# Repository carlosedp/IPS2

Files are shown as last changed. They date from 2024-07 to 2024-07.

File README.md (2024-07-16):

# IPS2

The infamous interruptible power supply is back version 2 with usbC and more mmpfh (700mA@12V / 500mA@-12V).

IPS is a 2HP opensource (cc-by-sa-nc) eurorack module. It’s a switched-mode power supply that converts the 5V power from any USB type C interface/charger into +12V/-12V for your modular synthesizer. This does not allow you to power big racks but can easily power up small to medium size systems (check powerconsumption with f.e. modulargrid.net)
You can also use the unit without frontpanel inside a case (no access to the SHUT inputs) if it has a power switch and a 5V input.

Unlike IPS1 this module is built around a monolytic IC which houses two independent regulators, the TPS65131 from TI. It still has the infamous shutdown inputs for the regulators, which are accessible thru two jacks on the frontpanel.
Quote from IPS1: “This gives you a very different approach to operate a connected module. By “proper” modulation of it’s own powersupply voltages any connected module(s) can operate then in a, let’s say:  “near death state”, which can create interesting effects.

DISCLAIMER:
The shutdown inputs are a very experimental feature for those who like to experiment on their own risk with reduced or chopped supply voltages for their modules/setup. We take no responibility for damage or the like. (should not occur, cause no inversion of voltage is possible, only reduction of voltage is possible)

In a glimpse:

- modern and fast 1.25MHz switching regulator from Texas Instruments deliver up to 700mA@12V and 500mA@-12V
- IPS mainboard can be mounted inside a case without frontpanel like a common PSU (flatmount, has 2nd location for USB C connector and also pads for wires)
- cheap – can be used with any USB type C charger
- it’s friggin tiny

In this fork, I've replaced the USB connectors to some more available on JLCPCB.

Also I've added a front-panel design that is connected to the PCB with break-tabs so they can
be easily manufactured in one run and separated. Components also have JLCPCB part numbers.

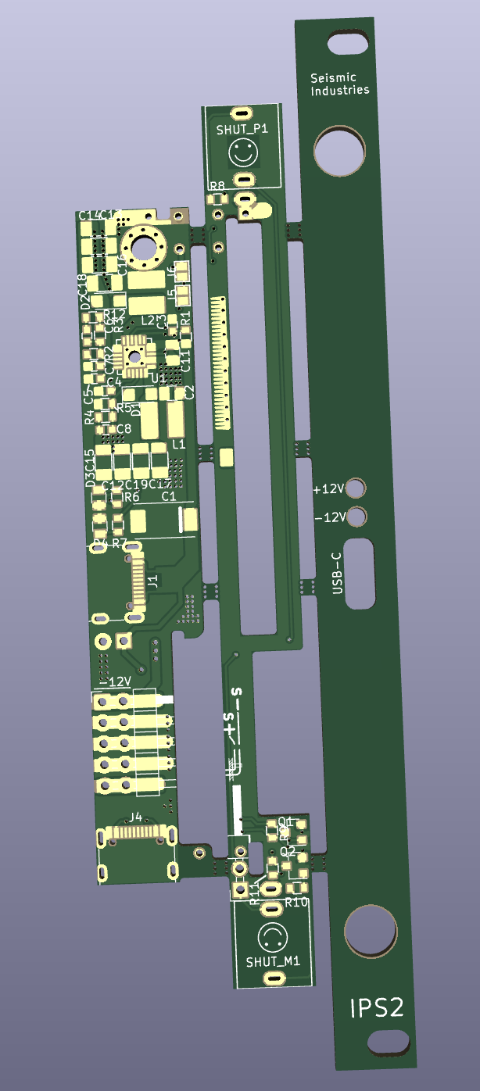
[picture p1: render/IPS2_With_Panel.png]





I/O:

- SHUT +12V deactivates the swiching regulator for the positive rail
- SHUT -12V deactivates the switching regulator for the negative rail
- internal 10 pin molex output header

Power Output:

- +12V 700mA / -12V 500mA (if incoming USB interface delivers it)

Dimensions:

- Width: 2 HP (10mm)
- Depth: 13mm

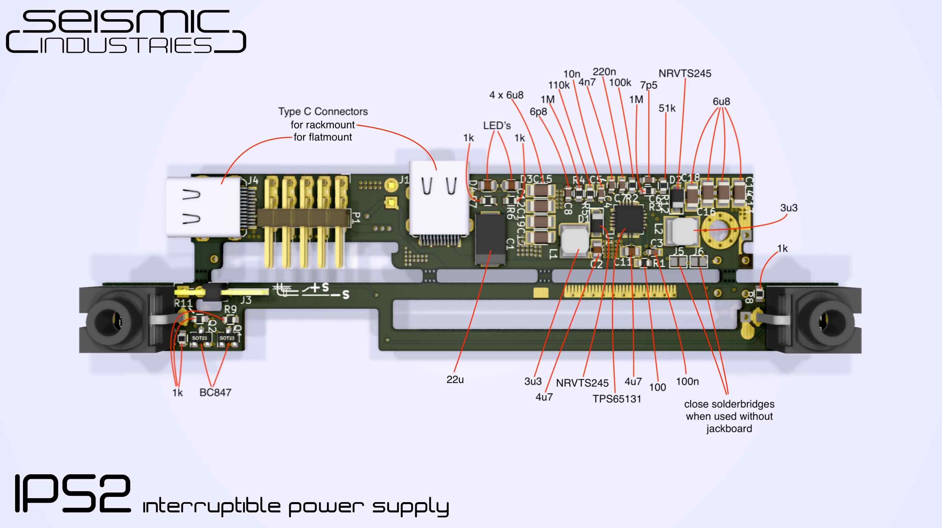
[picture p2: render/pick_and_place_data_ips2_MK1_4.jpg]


## License

CC-BY-SA-NC license

by seismic industries / 2019

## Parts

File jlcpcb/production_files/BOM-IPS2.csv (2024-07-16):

Comment | Designator | Footprint | LCSC
4u7 | L1,L2 | Inductor_SRN4018TA_bourns | C1330726
100n | C3 | C_0603 | C14663
Q_NPN_BEC | Q1,Q2 | SOT-23 | C150094
NRVTS245 | D1,D2 | D_SOD-123F | C154804
6p8 | C8 | C_0603 | C1679
4u7 | C11,C2 | C_0805 | C1779
220n | C7 | C_0603 | C21120
1k | R10,R11,R6,R7,R8,R9 | R_0603 | C21190
100 | R1 | R_0603 | C22775
1M | R3,R4 | R_0603 | C22935
51k | R12 | R_0603 | C23196
100k | R2 | R_0603 | C25803
110k | R5 | R_0603 | C25805
USB_C_Receptacle | J1,J4 | USB_C_Receptacle_G-Switch_GT-USB-7010ASV | C2988369
22u | C1 | CP_Elec_7.3x4.3 | C465932
7p5 | C6 | C_0603 | C53424
LED | D3,D4 | C_0805 | C5353439
4n7 | C5 | C_0603 | C53987
10n | C4 | C_0603 | C57112
6u8 | C12,C13,C14,C15,C16,C17,C18,C19 | C_1206 | C7393982
TPS65131 | U1 | QFN-24-4x4mm_Pitch0.5mm_handsolder_big_thermal_hole | C87663

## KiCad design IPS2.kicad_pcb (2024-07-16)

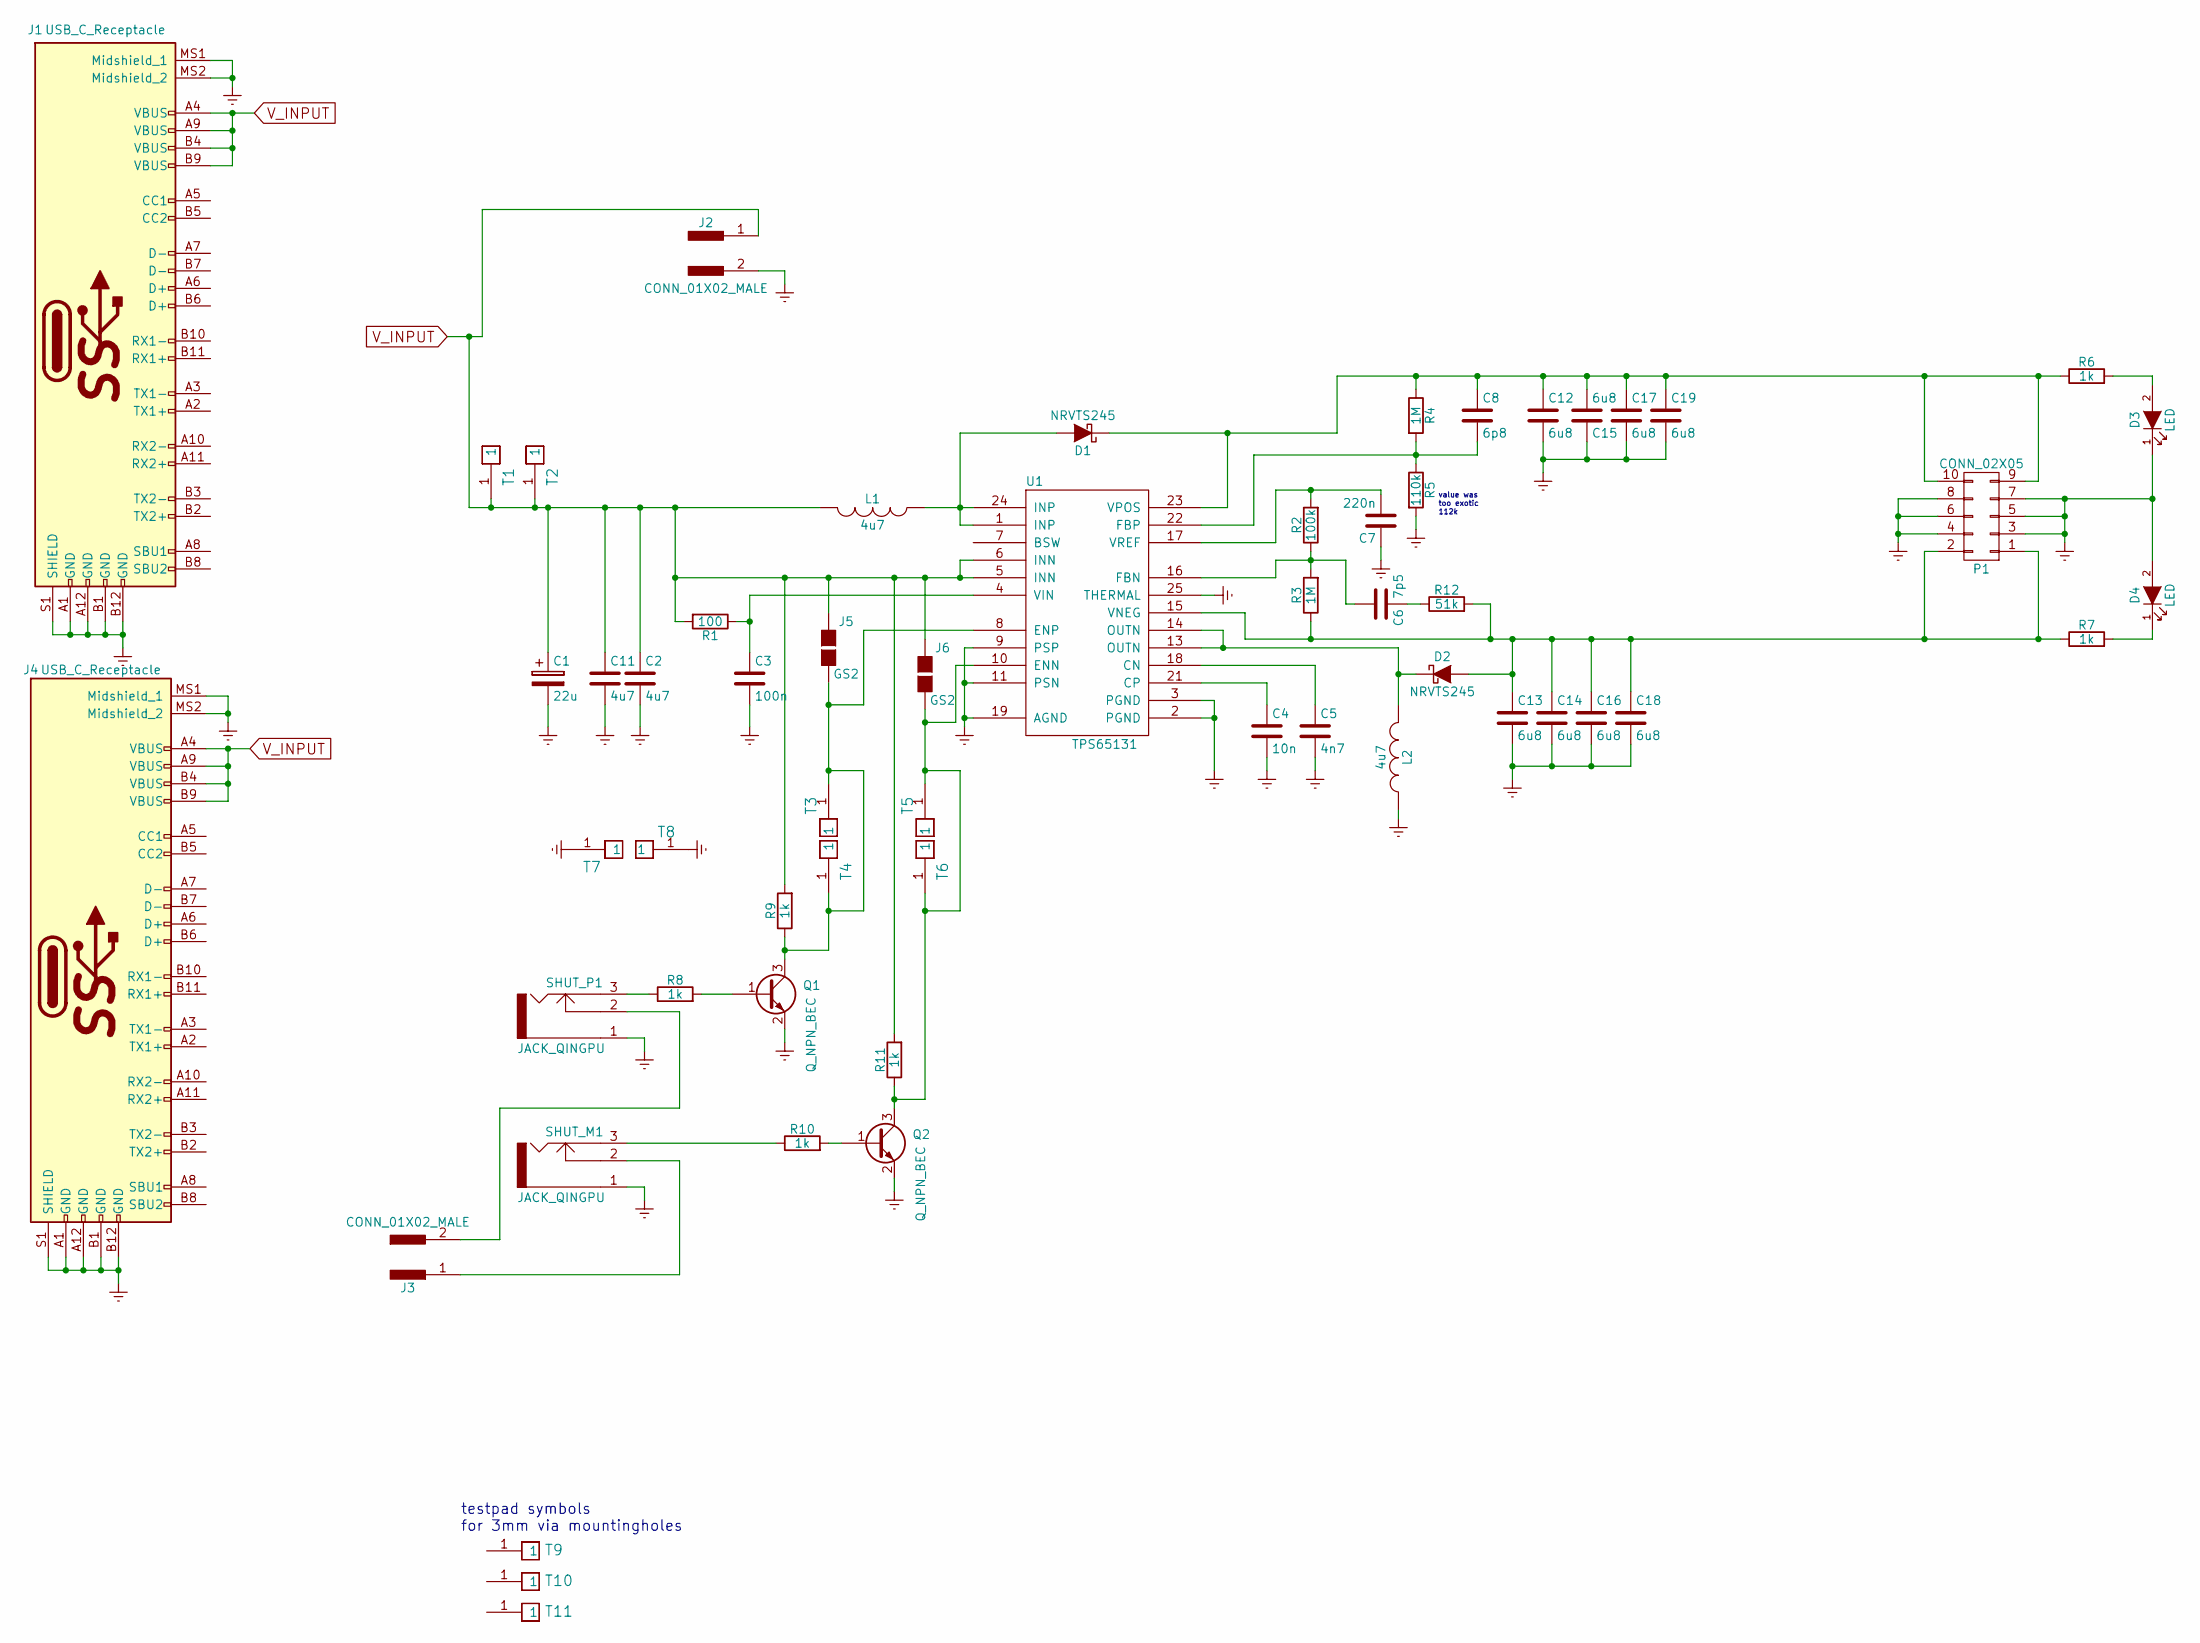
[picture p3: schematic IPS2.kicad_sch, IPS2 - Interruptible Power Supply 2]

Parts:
C1: 22u; CP_Elec_7.3x4.3; MPN EEF-CX1D220R; LCSC C465932
C2, C11: 4u7; C_0805; MPN GRM21BR61H475KE51L; LCSC C1779
C3: 100n; C_0603; MPN C0603C104Z3VACTU; LCSC C14663
C4: 10n; C_0603; MPN 885012206065; LCSC C57112
C5: 4n7; C_0603; MPN 885012206087; LCSC C53987
C6: 7p5; C_0603; MPN GRM1885C1H7R5BA1D; LCSC C53424
C7: 220n; C_0603; MPN CC603KRX7R7BB224; LCSC C21120
C8: 6p8; C_0603; MPN 885012006050; LCSC C1679
C12, C13, C14, C15, C16, C17, C18, C19: 6u8; C_1206; MPN C3216X7R1E685K160AB; LCSC C7393982
D1, D2: NRVTS245; D_SOD-123F; MPN NRVTS245ESFT3G; LCSC C154804
D3, D4: LED; C_0805; MPN APT2012SGC; LCSC C5353439
J1, J4: USB_C_Receptacle; USB_TYPE_C_WUERTH_632723300011; MPN 632723300011; LCSC C2988369
J2: CONN_01X02_MALE; Pin_Header_Angled_1x02_Pitch2.54mm
J3: CONN_01X02_MALE; Pin_Header_Angled_2x01_Pitch2.54mm
J5, J6: GS2
L1, L2: 4u7; Inductor_SRN4018TA_bourns; MPN SRN4018TA-4R7M; LCSC C1330726
P1: CONN_02X05; Pin_Header_Angled_2x05_Pitch2.54mm_with_space_for_con; MPN 649-68020-110HLF
Q1, Q2: Q_NPN_BEC; SOT-23; MPN BC847CLT1G; LCSC C150094
R1: 100; R_0603; MPN CRCW0603100RFKEAC; LCSC C22775
R2: 100k; R_0603; MPN RCA0603100KJNEC; LCSC C25803
R3, R4: 1M; R_0603; MPN RC0603FR-071ML; LCSC C22935
R5: 110k; R_0603; MPN CR0603-FX-1103ELF; LCSC C25805
R6, R7, R8, R9, R10, R11: 1k; R_0603; MPN RC0603FR-071KL; LCSC C21190
R12: 51k; R_0603; MPN RC0603FR-0751KL; LCSC C23196
SHUT_M1: JACK_QINGPU; jack_qingpu
SHUT_P1: JACK_QINGPU; jack_qingpu
T1, T2, T3, T4, T5, T6, T7, T8: TESTPIN; TESTPAD_SMD_and_THT_SQR
T9, T10, T11: TESTPIN; VIA_M3_mounting_hole
U1: TPS65131; QFN-24-4x4mm_Pitch0.5mm_handsolder_big_thermal_hole; MPN TPS65131RGER; LCSC C87663

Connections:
Earth: C1.2, C2.2, C3.2, C4.2, C5.2, C7.1, C11.2, C12.2, C13.2, C14.2, C15.1, C16.2, C17.2, C18.2, C19.2, D3.1 (K), D4.2 (A), J1.A1 (GND), J1.A12 (GND), J1.B1 (GND), J1.B12 (GND), J1.MS1 (Midshield_1), J1.MS2 (Midshield_2), J1.S1 (SHIELD), J2.2, J4.A1 (GND), J4.A12 (GND), J4.B1 (GND), J4.B12 (GND), J4.MS1 (Midshield_1), J4.MS2 (Midshield_2), J4.S1 (SHIELD), L2.1, P1.3, P1.4, P1.5, P1.6, P1.7, P1.8, Q1.2 (E), Q2.2 (E), R5.2, SHUT_M1.1, SHUT_P1.1, T7.1, T8.1, U1.2 (PGND), U1.3 (PGND), U1.9 (PSP), U1.11 (PSN), U1.19 (AGND), U1.25 (THERMAL)
unnamed: C3.1, R1.1, U1.4 (VIN)
unnamed: C4.1, U1.21 (CP)
unnamed: C5.1, U1.18 (CN)
unnamed: C6.1, R12.1
unnamed: C6.2, R2.1, R3.2, U1.16 (FBN)
unnamed: C7.2, R2.2, U1.17 (VREF)
unnamed: C8.2, R4.2, R5.1, U1.22 (FBP)
unnamed: C8.1, C12.1, C15.2, C17.1, C19.1, D1.1 (K), P1.9, P1.10, R4.1, R6.1, U1.23 (VPOS)
unnamed: C13.1, C14.1, C16.1, C18.1, D2.2 (A), P1.1, P1.2, R3.1, R7.1, R12.2, U1.15 (VNEG)
unnamed: D1.2 (A), L1.1, U1.1 (INP), U1.24 (INP)
unnamed: D2.1 (K), L2.2, U1.13 (OUTN), U1.14 (OUTN)
unnamed: D3.2 (A), R6.2
unnamed: D4.1 (K), R7.2
unnamed: J3.1, SHUT_M1.2
unnamed: J3.2, SHUT_P1.2
unnamed: J5.2 (G2), Q1.3 (C), R9.1, T3.1, T4.1, U1.8 (ENP)
unnamed: J6.2 (G2), Q2.3 (C), R11.1, T5.1, T6.1, U1.10 (ENN)
unnamed: Q1.1 (B), R8.2
unnamed: Q2.1 (B), R10.2
unnamed: R8.1, SHUT_P1.3
unnamed: R10.1, SHUT_M1.3
V_INPUT: C1.1, C2.1, C11.1, J1.A4 (VBUS), J1.A9 (VBUS), J1.B4 (VBUS), J1.B9 (VBUS), J2.1, J4.A4 (VBUS), J4.A9 (VBUS), J4.B4 (VBUS), J4.B9 (VBUS), J5.1 (G1), J6.1 (G1), L1.2, R1.2, R9.2, R11.2, T1.1, T2.1, U1.5 (INN), U1.6 (INN)

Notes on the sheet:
testpad symbols for 3mm via mountingholes
value was too exotic 112k

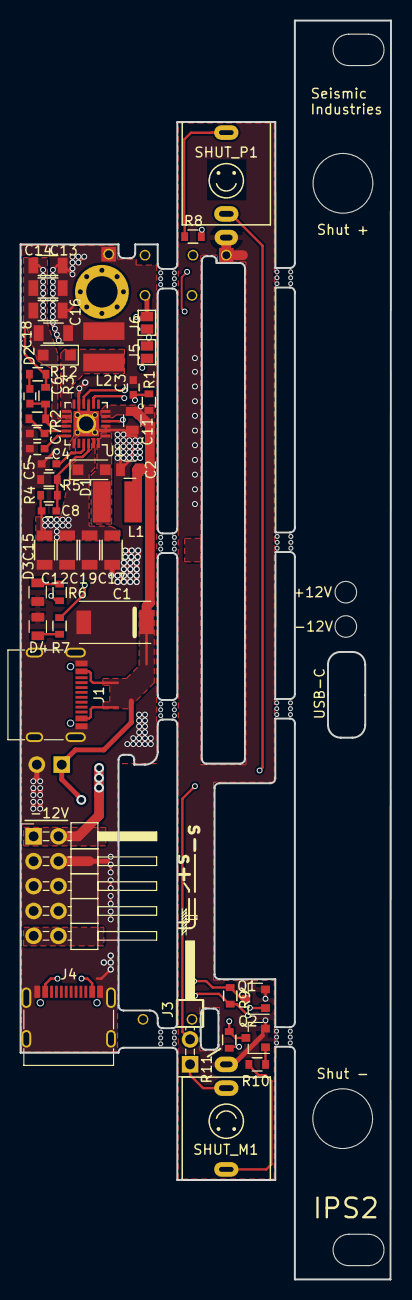
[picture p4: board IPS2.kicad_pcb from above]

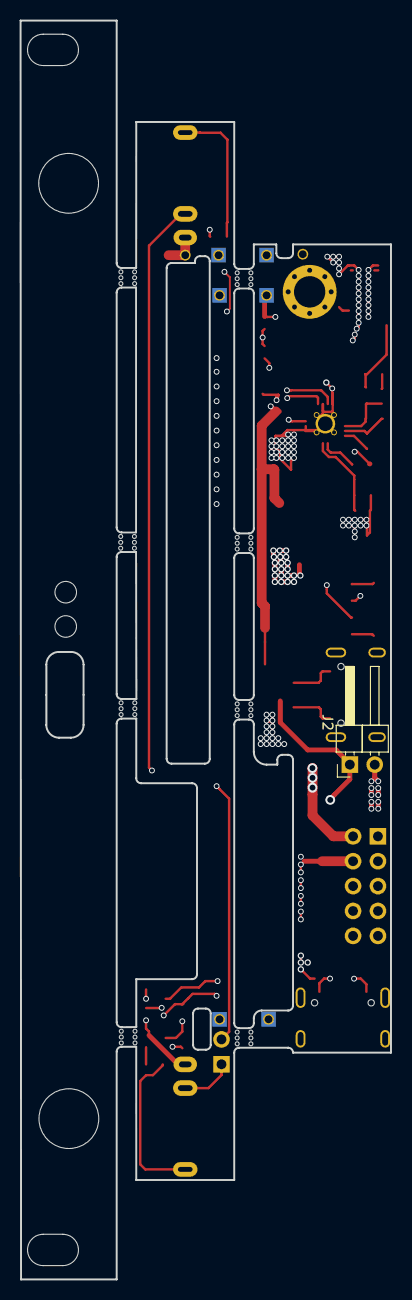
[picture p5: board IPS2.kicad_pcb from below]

Board: 2 copper layers, 37.8 x 128.5 mm, 56 parts (7 on the bottom side), 23 nets.

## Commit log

2024-07-16 Update PCB with linked panel with break-tab. Changed USB socket.
    [IPS2.kicad_pcb, IPS2.kicad_sch]
2024-07-16 Added JLCPCB parts mapping and Gerbers using Bouni/kicad-jlcpcb-tools plugin
    [BOM-IPS2.csv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]
2024-07-16 Add labels to shut jacks. Update readme.
    [IPS2-CuBottom.gbr, IPS2-CuTop.gbr, IPS2-EdgeCuts.gbr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]
2024-07-16 Clean old files
    [IPS2.sch]
